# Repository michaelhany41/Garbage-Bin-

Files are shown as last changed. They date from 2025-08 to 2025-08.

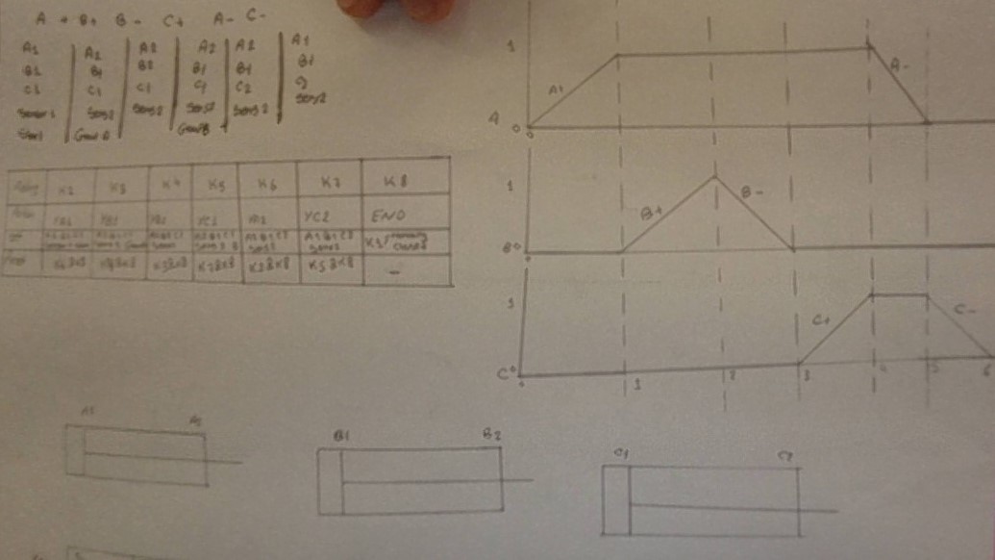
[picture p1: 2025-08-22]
step diagram1.jpg

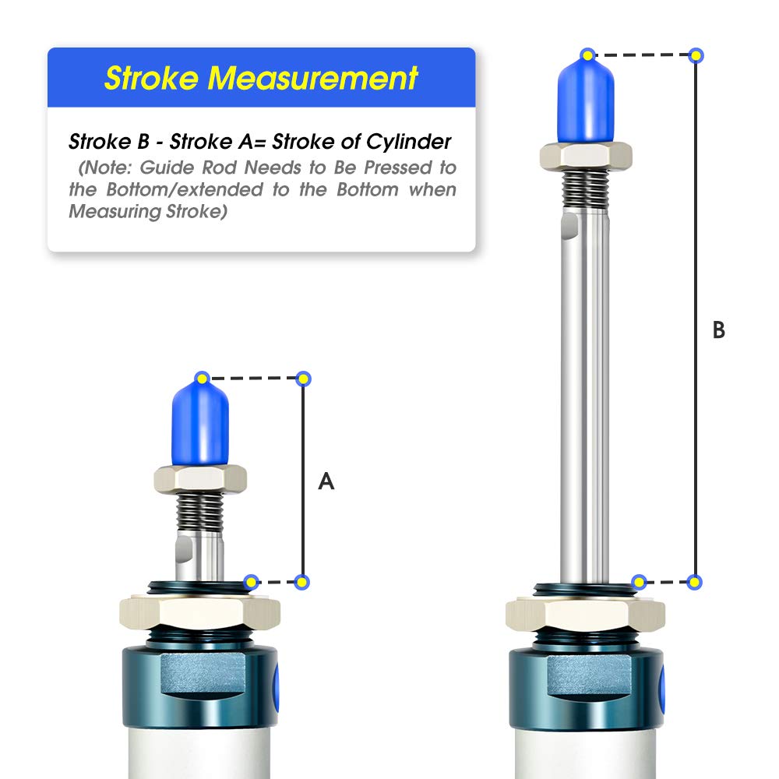
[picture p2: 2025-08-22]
SolidWorks design/Pneumatic Air Cylinder Double Action/3.jpg

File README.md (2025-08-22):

# Garbage-Bin-
This project showcases an automated garbage handling system using pneumatic cylinders, sensors, and relay-based control. The system detects garbage, pushes it into a crushing chamber, compresses it, and then disposes of it into a bin — all in a fully automated sequence.

⚙️ How It Works

Detection: Two photocell sensors detect incoming garbage.

Push to Crusher: Cylinder 1 pushes the garbage into the crushing chamber.

Crushing: Cylinder 2 compresses the garbage.

Disposal: Cylinder 3 ejects the compacted waste into a bin.

🛠️ Components

3 Pneumatic Cylinders

11 Relays

6 Reed Switches (2 per cylinder for position feedback)

2 Photocell Sensors

Solenoid Valves

Power Supply & Relay Logic

🧠 Control Logic

The system uses reed switches and relays to manage the sequence and ensure each cylinder operates only when safe. Relays control solenoids based on sensor input, enabling fully automated, reliable operation without a microcontroller.

📦 Applications

Ideal for educational automation demos, small-scale prototyping of waste management systems, or learning electropneumatics and sensor integration.

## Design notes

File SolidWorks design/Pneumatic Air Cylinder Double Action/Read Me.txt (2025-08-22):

This 3D model shows a pneumatic cylinder of four different sizes.
The cylinder length can be customized by adjusting the stroke using equations in SolidWorks for the Cylinder Barrel and Piston Rod.
Detailed stroke lengths are available in the provided "Product Description" PDF.

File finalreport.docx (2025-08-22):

# German University in Cairo

# Mechatronics Lab (MCTR704)

# Automated Garbage Bin

# Project No. [4]

Name: Michael Hany /Khaled Hussien

I.D #: 55-23395 /55-6752

Tutorial No.: 28

Table of Contents

Milestone No./ Submission Date | Content | Page
Milestone 1 23/09/2024 | Project Description……………………………………………………………….. | x-x
Milestone 1 23/09/2024 | SolidWorks Design: 3D Schematic Diagram………...................... | x-x
Milestone 2 14/10/2024 | Mechanical Components in 2D with Dimensions…………………… | x-x
Milestone 2 14/10/2024 | Mechanical Components List………………………………………………… | x-x
Milestone 3 11/11/2024 | Pneumatic Step Diagram………………………………………………………. | x-x
Milestone 3 11/11/2024 | Electro-Pneumatic Circuit……………………………………………………… | x-x
Milestone 4 09/12/2024 | Hardware Model (Electrical + Mechanical)……………………………. | x-x
Milestone 4 xx/12/2024 | Fully Operating Hardware (Final Evaluation)…………………………. | x-x

Project Description:

Dimensions:

Frame 90cm X 70cm X 90cm

Project Idea:

The Automated Garbage Bin consists of a compact machine with a sturdy, ground-seated frame that supports three hydraulic cylinders and integrated sensors. The frame holds all the necessary mechanical components, and the system is designed to manage garbage collection and compaction efficiently. Various actuators and sensors are used to automate the entire operation.

Objective:

This project aims to collect and compress garbage, reducing its volume for more efficient storage and disposal and save more space also for the environment

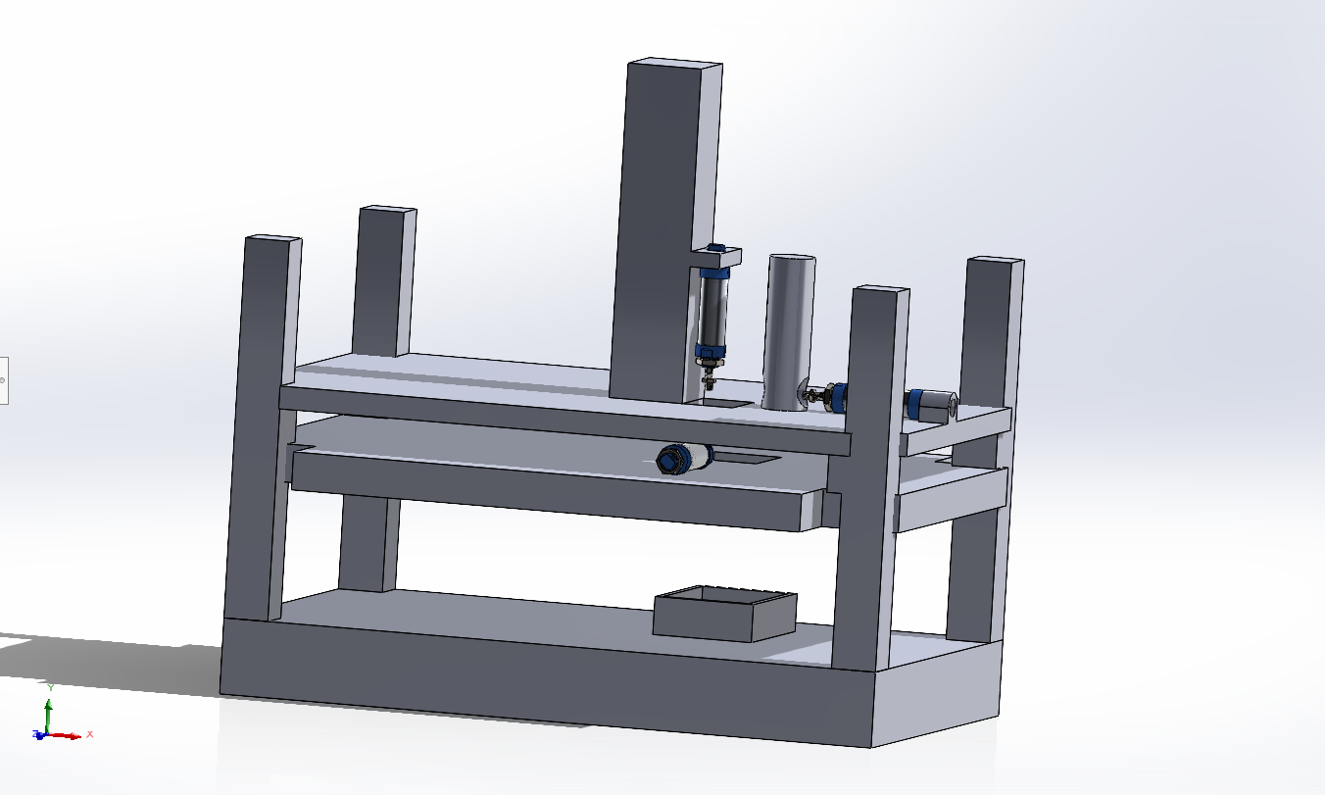
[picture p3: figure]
A 3d model of a machine with Willis Tower in the background

Process:

This machine features a ground-level frame that supports all mechanical components, including three hydraulic cylinders and various sensors. Here's how it works:

1. Garbage is placed into a container.
2. First, the garbage is dropped into the receiving container.
3. When the sensors sense the garbage the first cylinder [A] moves the garbage from the bin into a compression chamber.
4. The second cylinder [B] which is in a vertical mode, compresses the garbage.
5. Once compressed, the third cylinder ejects the compacted garbage from the machine to the trash.

SolidWorks Design: 3D Schematic Diagram

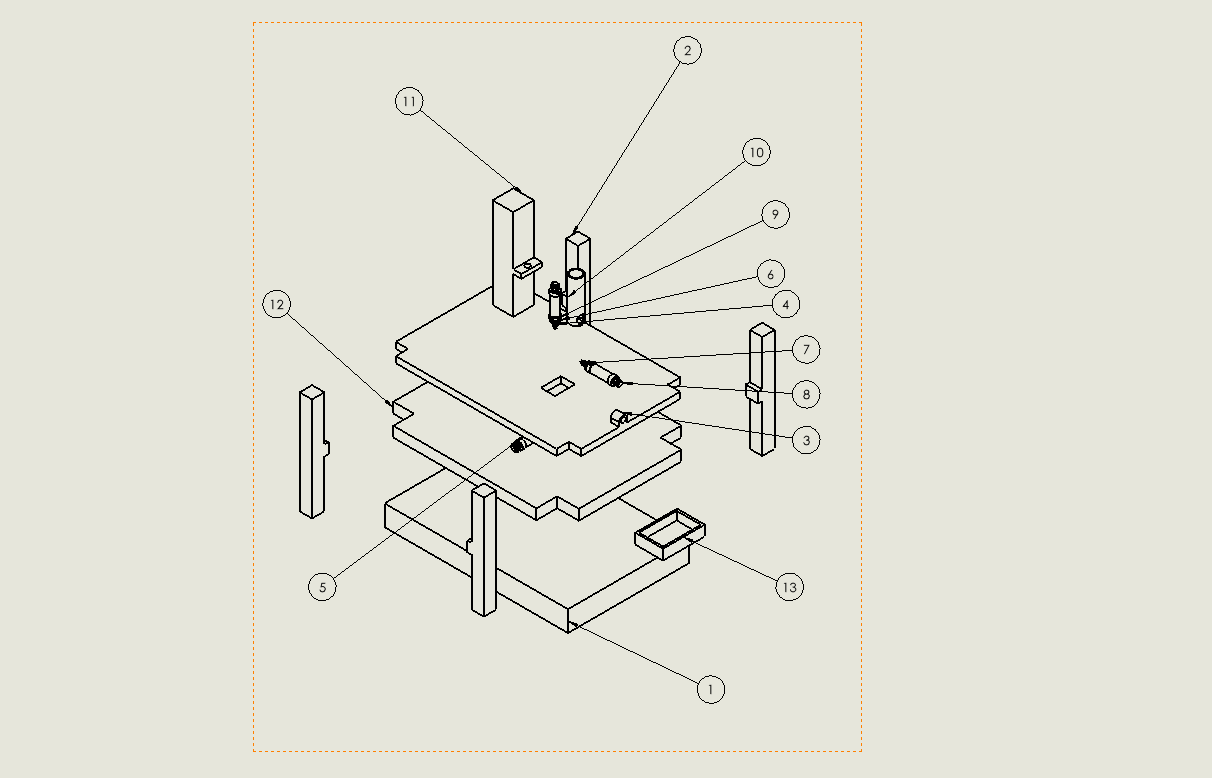
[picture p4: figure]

Part Number | Name | Quantity
1 | Ground base | 1
2 | Support Bar | 4
3 | Level 2 base | 3
4 | Cylinder A Piston | 1
5 | Cylinder C | 1
6 | Cylinder A | 1
7 | Cylinder B piston | 1
8 | Cylinder B | 1
9 | Cup Cylinder | 1
10 | Cylinder A nut | 1
11 | Cylinder B Holder | 1
12 | Level 1 base | 1
13 | Garbage basket | 1

Project Documentation Winter 20241Mechatronics Lab MCTR704

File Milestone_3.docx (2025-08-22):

# German University in Cairo

# Mechatronics Lab (MCTR704)

# Automated Garbage Bin

# Project No. [4]

Name: Michael Hany /Khaled Hussien

I.D #: 55-23395 /55-6752

Tutorial No.: 28

Table of Contents

Milestone No./ Submission Date | Content | Page
Milestone 1 23/09/2024 | Project Description……………………………………………………………….. | x-x
Milestone 1 23/09/2024 | SolidWorks Design: 3D Schematic Diagram………...................... | x-x
Milestone 2 14/10/2024 | Mechanical Components in 2D with Dimensions…………………… | x-x
Milestone 2 14/10/2024 | Mechanical Components List………………………………………………… | x-x
Milestone 3 11/11/2024 | Pneumatic Step Diagram………………………………………………………. | x-x
Milestone 3 11/11/2024 | Electro-Pneumatic Circuit……………………………………………………… | x-x
Milestone 4 09/12/2024 | Hardware Model (Electrical + Mechanical)……………………………. | x-x
Milestone 4 xx/12/2024 | Fully Operating Hardware (Final Evaluation)…………………………. | x-x

Project Description:

Dimensions:

Frame 90cm X 70cm X 90cm

Workpiece is a paper cup diameter 6.5cm and height 10cm

Project Idea:

The Automated Garbage Bin consists of a compact machine with a sturdy, ground-seated frame that supports three hydraulic cylinders and integrated sensors. The frame holds all the necessary mechanical components, and the system is designed to manage garbage collection and compaction efficiently. Various actuators and sensors are used to automate the entire operation.

Objective:

This project aims to collect and compress garbage, reducing its volume for more efficient storage and disposal and save more space also for the environment

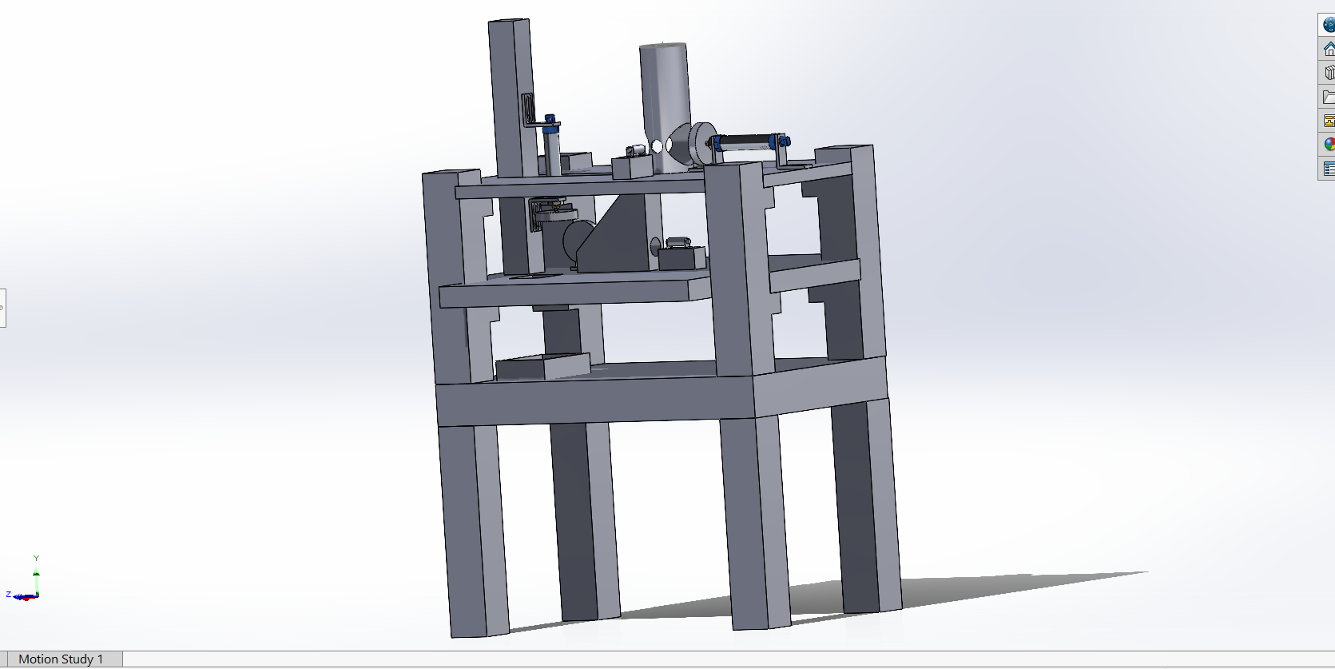
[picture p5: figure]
A grey machine with blue tubes

Process:

This machine features a ground-level frame that supports all mechanical components, including three hydraulic cylinders and various sensors. Here's how it works:

1. Garbage is placed into a container.
2. First, the garbage is dropped into the receiving container.
3. When the sensors sense the garbage the first cylinder [A] moves the garbage from the bin into a compression chamber.
4. The second cylinder [B] which is in a vertical mode, compresses the garbage.
5. Once compressed, the third cylinder ejects the compacted garbage from the machine to the trash.

SolidWorks Design: 3D Schematic Diagram

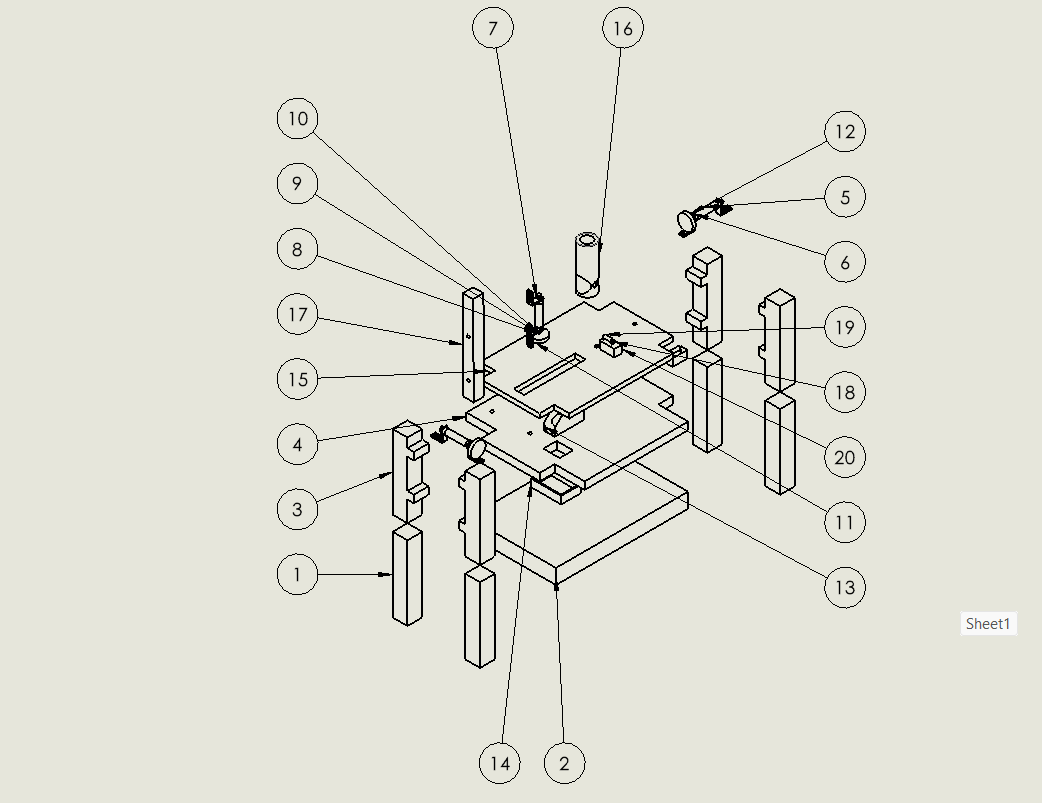
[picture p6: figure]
A diagram of a structure

Part Number | Name | Quantity
1 | Table leg | 4
2 | Ground base | 1
3 | Support bar | 4
4 | First level base | 1
5 | Cylinder A | 1
6 | bracket | 2
7 | Cylinder B | 1
8 | bracket | 6
9 | washer | 1
10 | End effector B | 1
11 | Nut | 1
12 | End effector A | 1
13 | Ramp | 1
14 | Garbage basket | 1
15 | Level 2 base | 1
16 | magazine | 1
17 | Cylinder B supporter | 1
18 | Sensor bracket | 4
19 | Sensor | 2
20 | Sensor Holder | 2

## Mechanical Components 2D Projections with Dimensions

Ramp

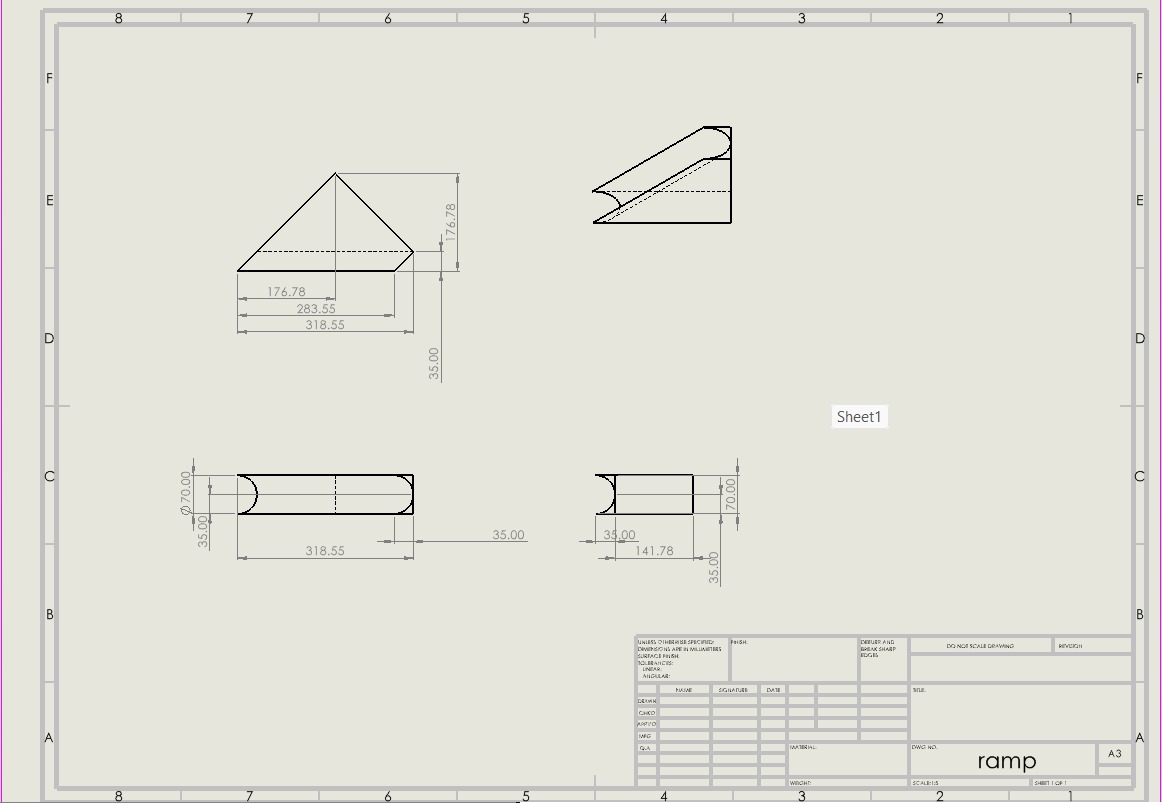
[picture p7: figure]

Supporter

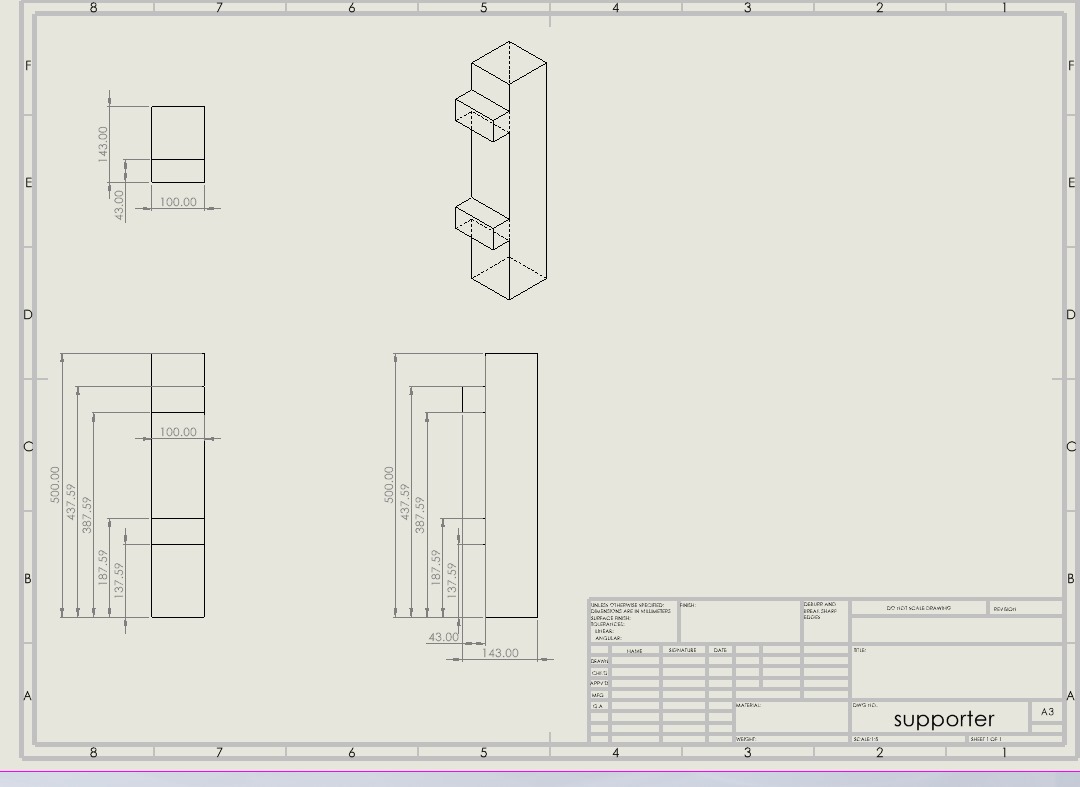
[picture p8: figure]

Tablet:

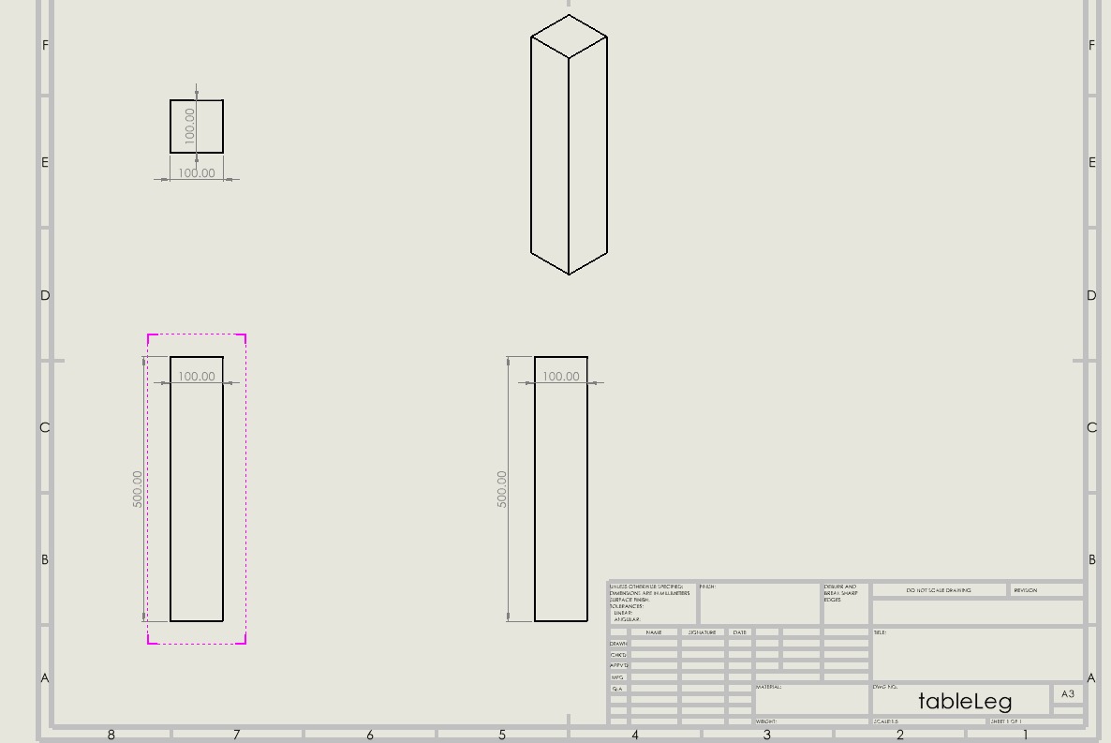
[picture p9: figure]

Cylinder Hold

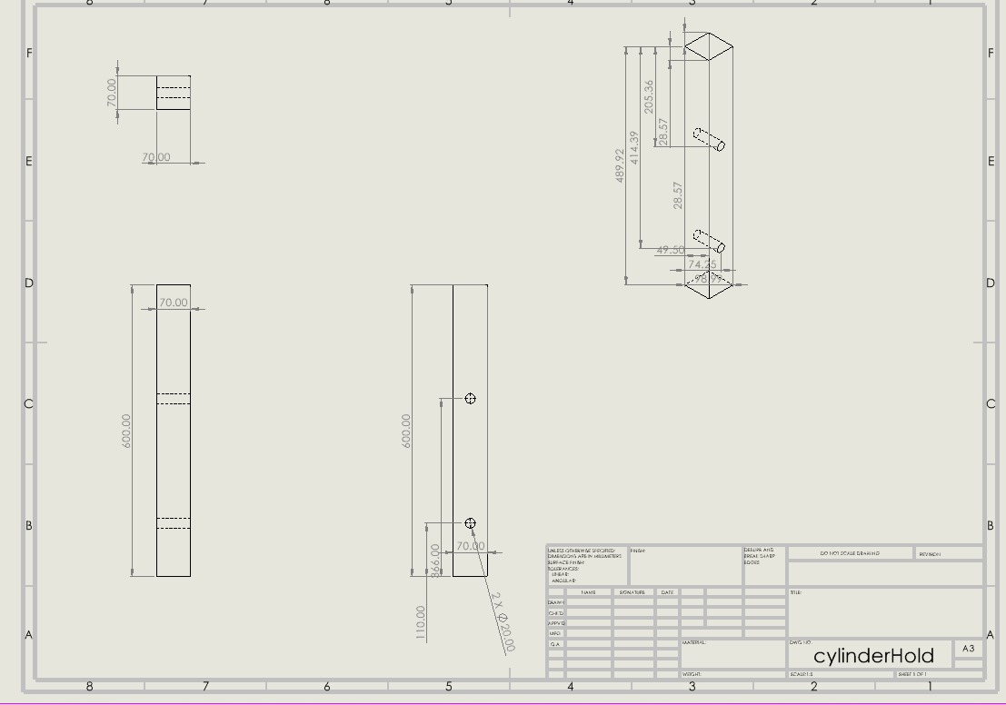
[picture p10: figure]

Base el Base

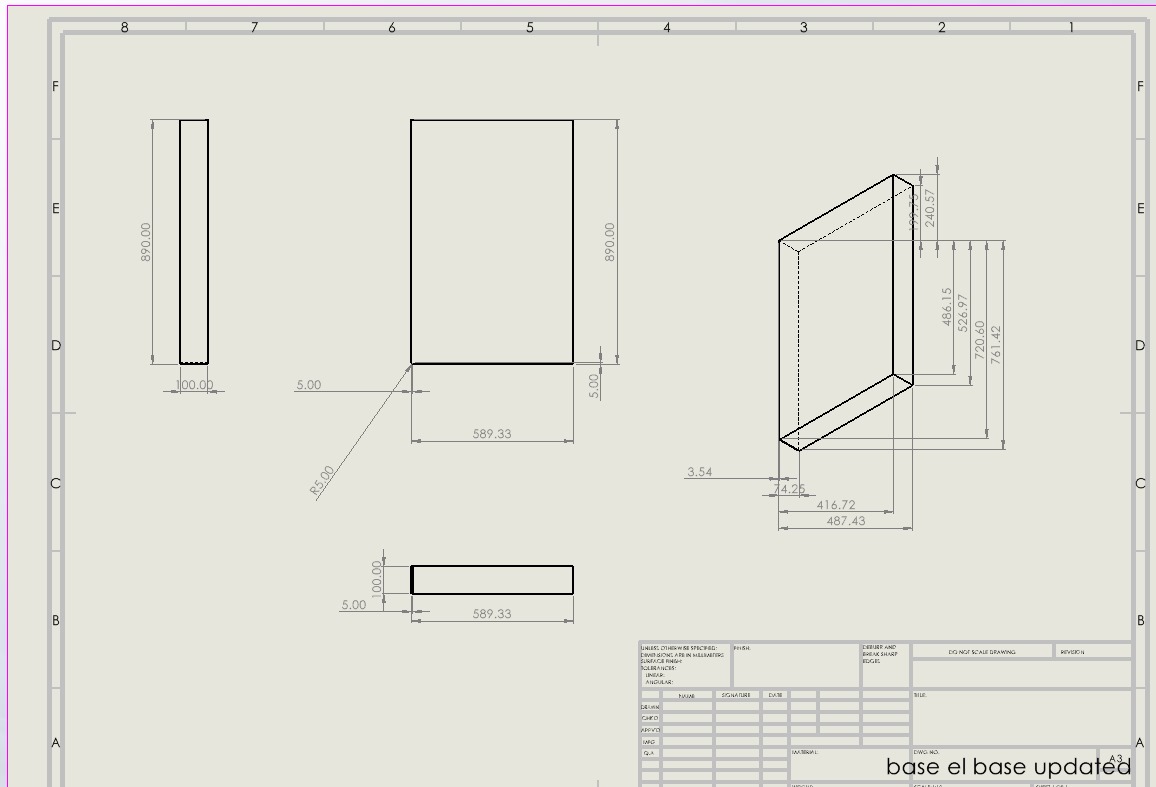
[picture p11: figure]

End Effector

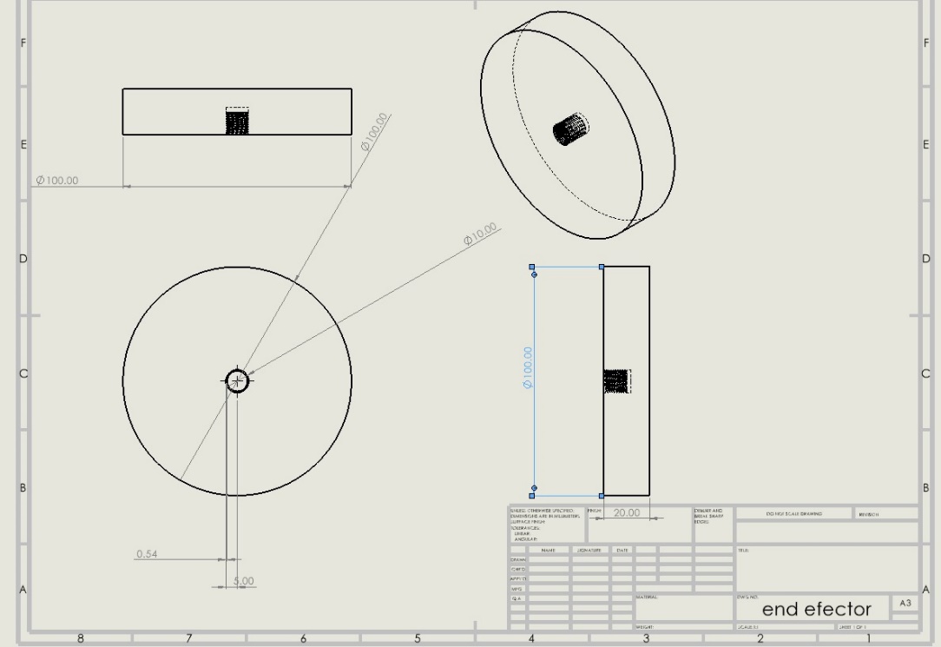
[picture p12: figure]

Pneumatic Air Cylinder Double Acting

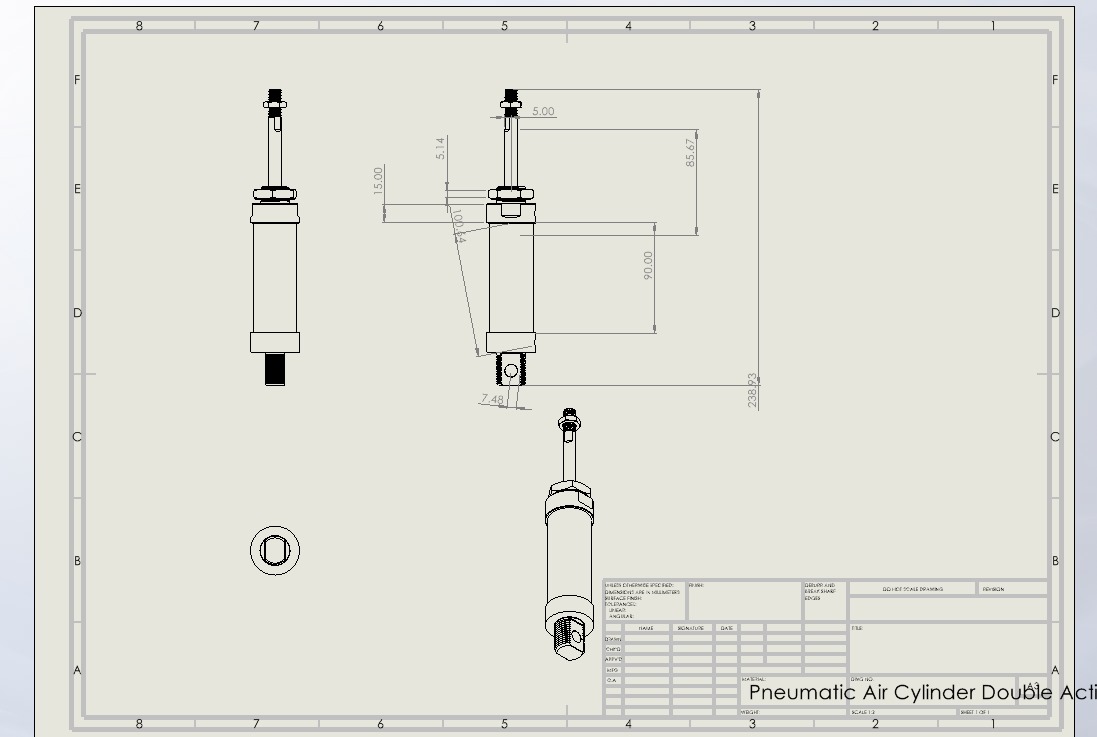
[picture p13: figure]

Base el Base

Bracket

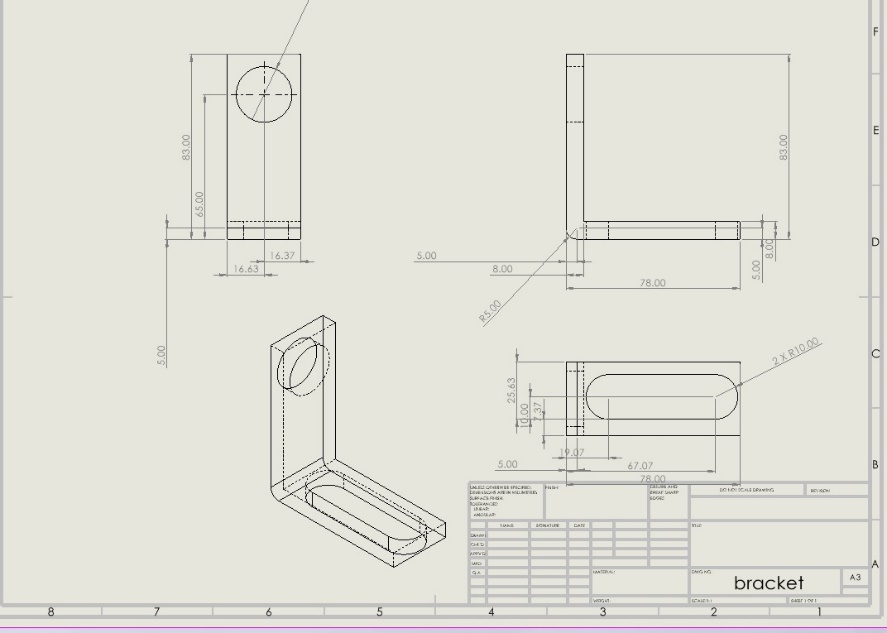
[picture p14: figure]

Magazine

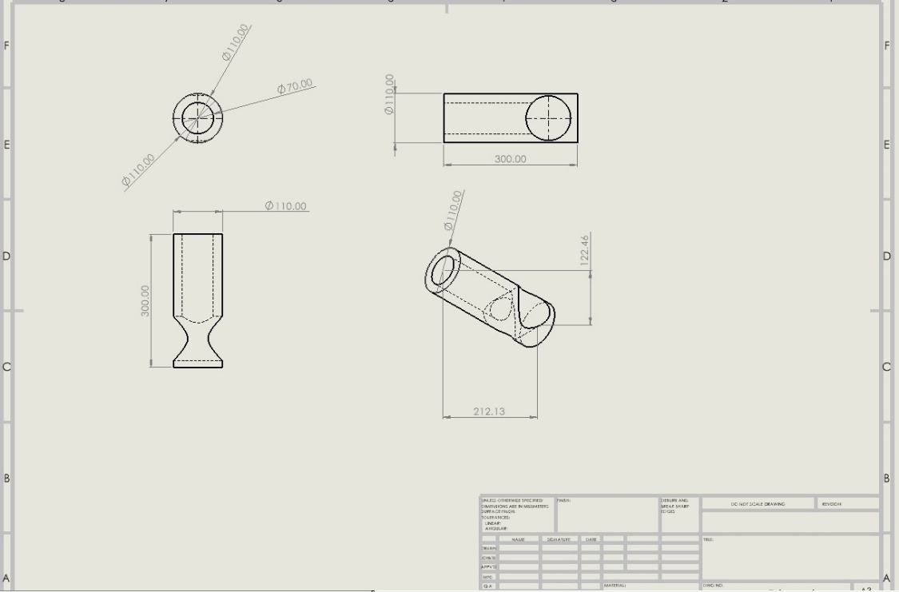
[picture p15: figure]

Sensor

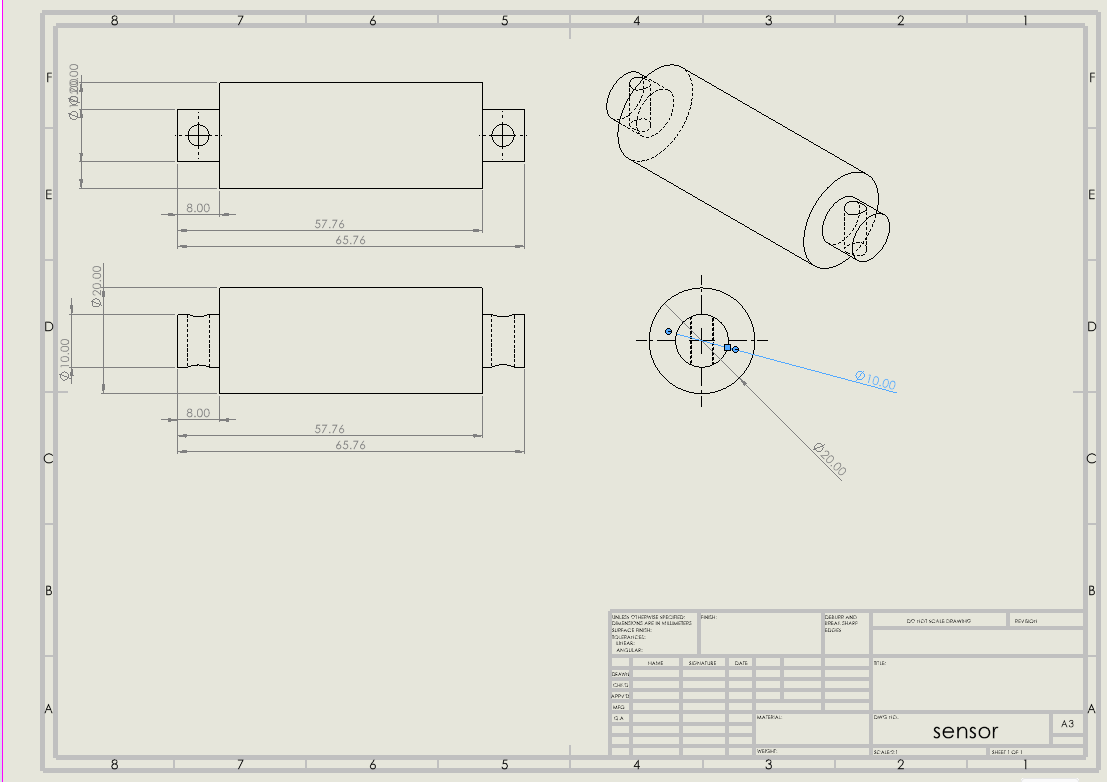
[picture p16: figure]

+

Component’s List:

Component’s Name | Picture | Quantity And Functions

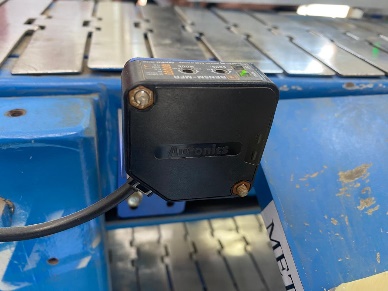
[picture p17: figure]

Photoelectric Sensor (ben5m-mfr) | | 2 Function: To detect the garbage and send electrical signal to the cylinder to function it

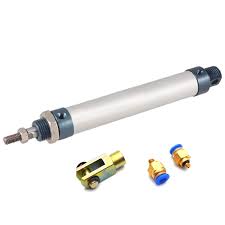
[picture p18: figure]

Pneumatic air cylinder double action | | 3 Function : Are used to transport and compress the gargbage

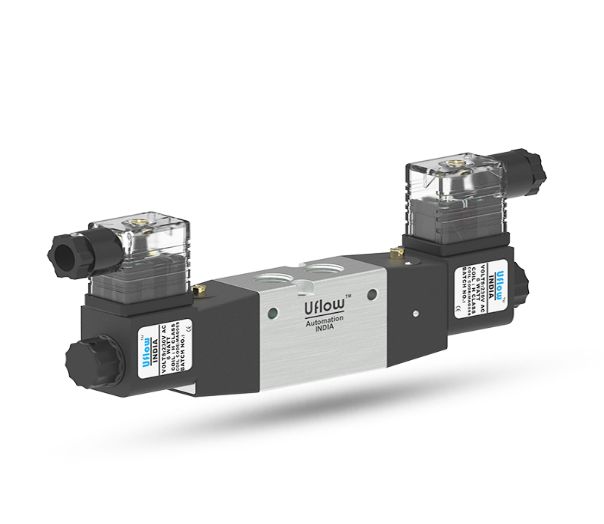
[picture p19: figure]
A close-up of a machine

5/2 pneumatic valves | | 3 Function : restore the pulses and make it continues

Pneumatic step diagram and description

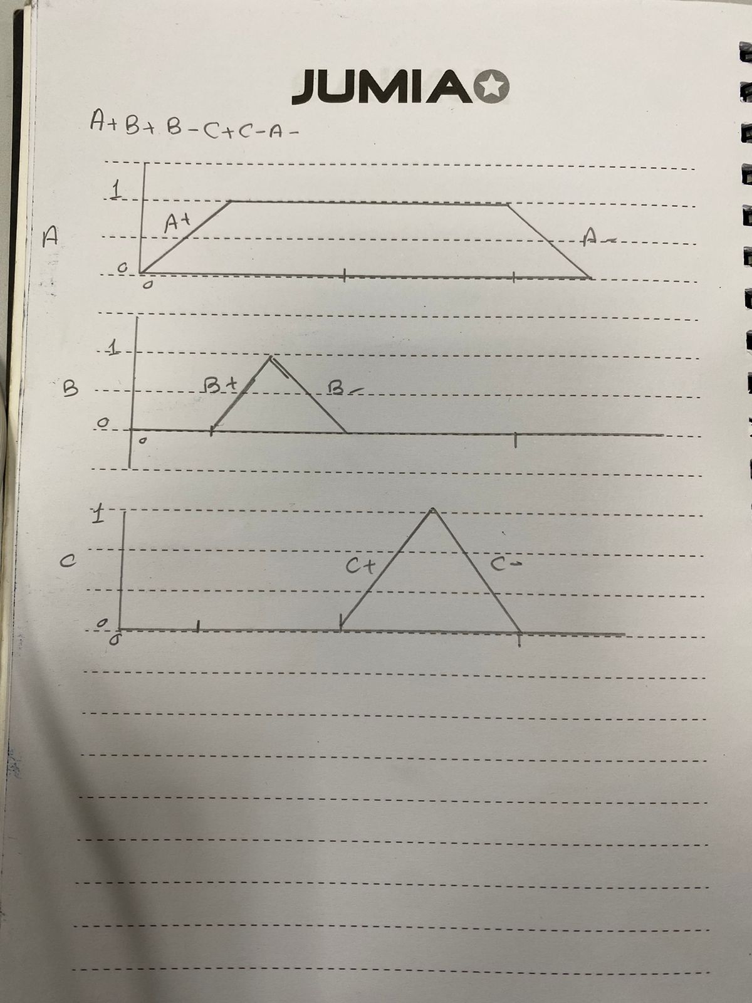
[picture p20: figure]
A notebook with lines drawn on it

As shown in figure the operation will start with Cylinder A extend

Then cylinder B will crash the object by extending then retracting

And Cylinder C will get rid of the object by extending

Then Cylinder A will retract after it ,Cylinder C will retract to start again the sequence

Electro pneumatic circuit

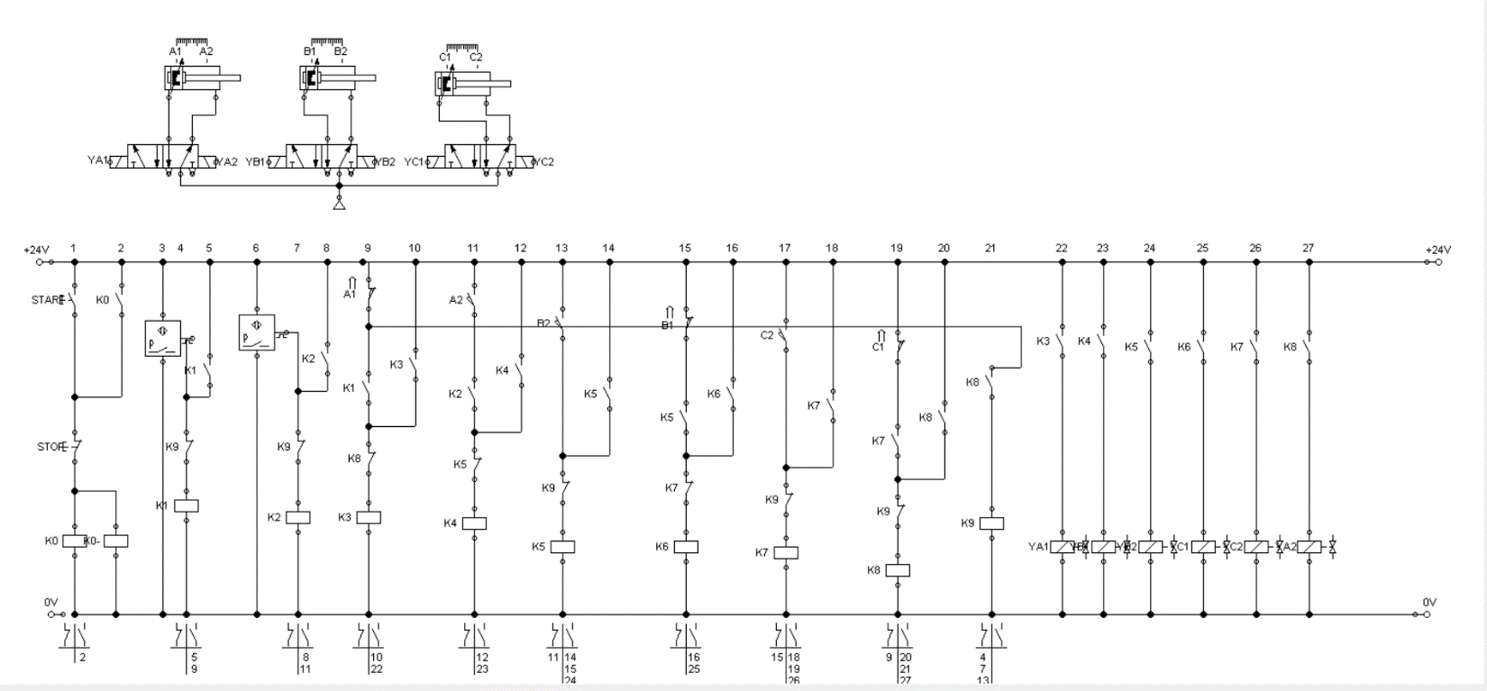
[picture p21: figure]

Hardware Model (Electrical + Mechanical):

Frame:

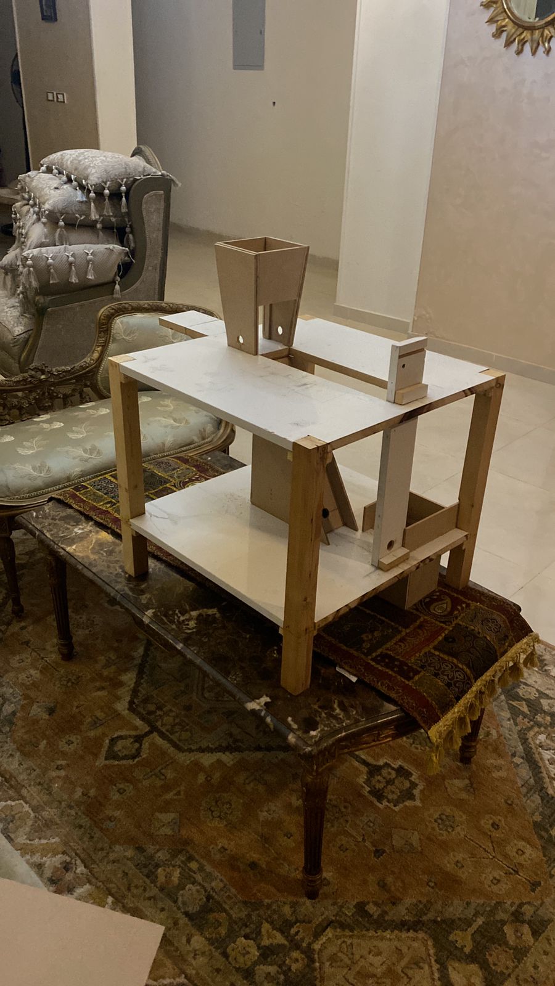
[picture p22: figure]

Control panel:

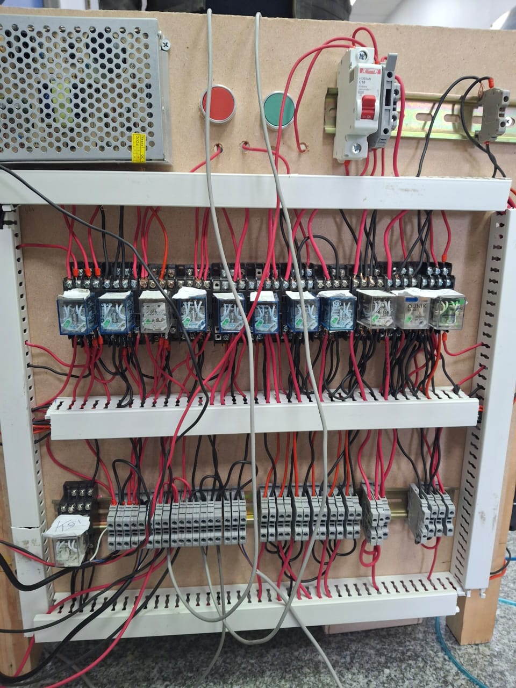
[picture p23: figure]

Final hardware:

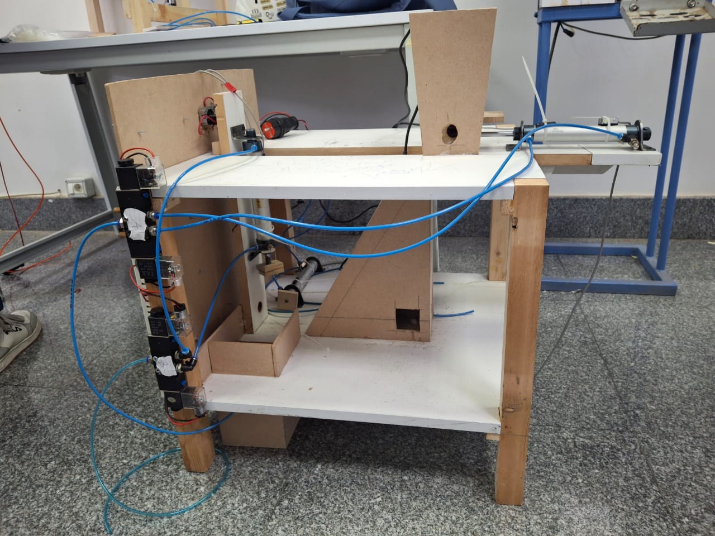
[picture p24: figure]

Project Documentation Winter 20241Mechatronics Lab MCTR704

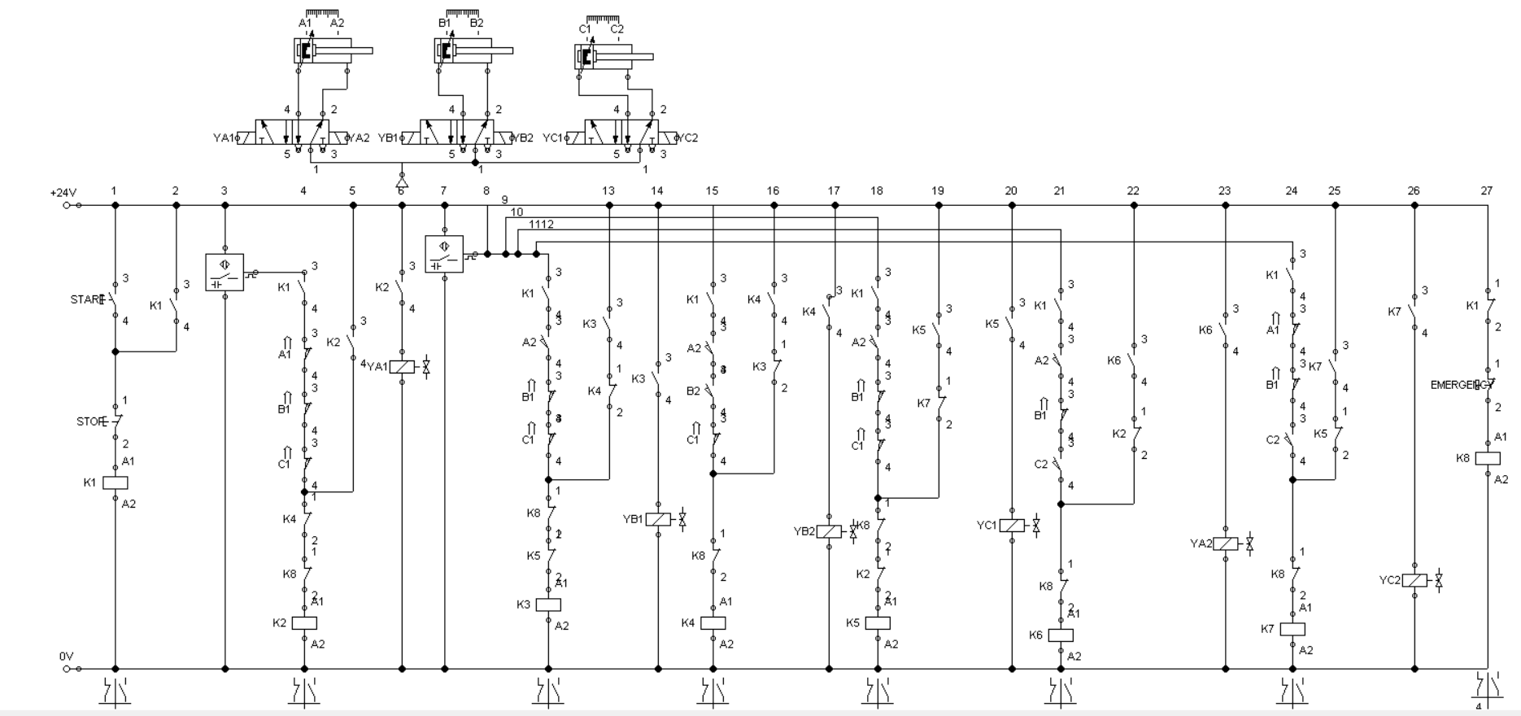
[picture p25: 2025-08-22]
project classic1.png

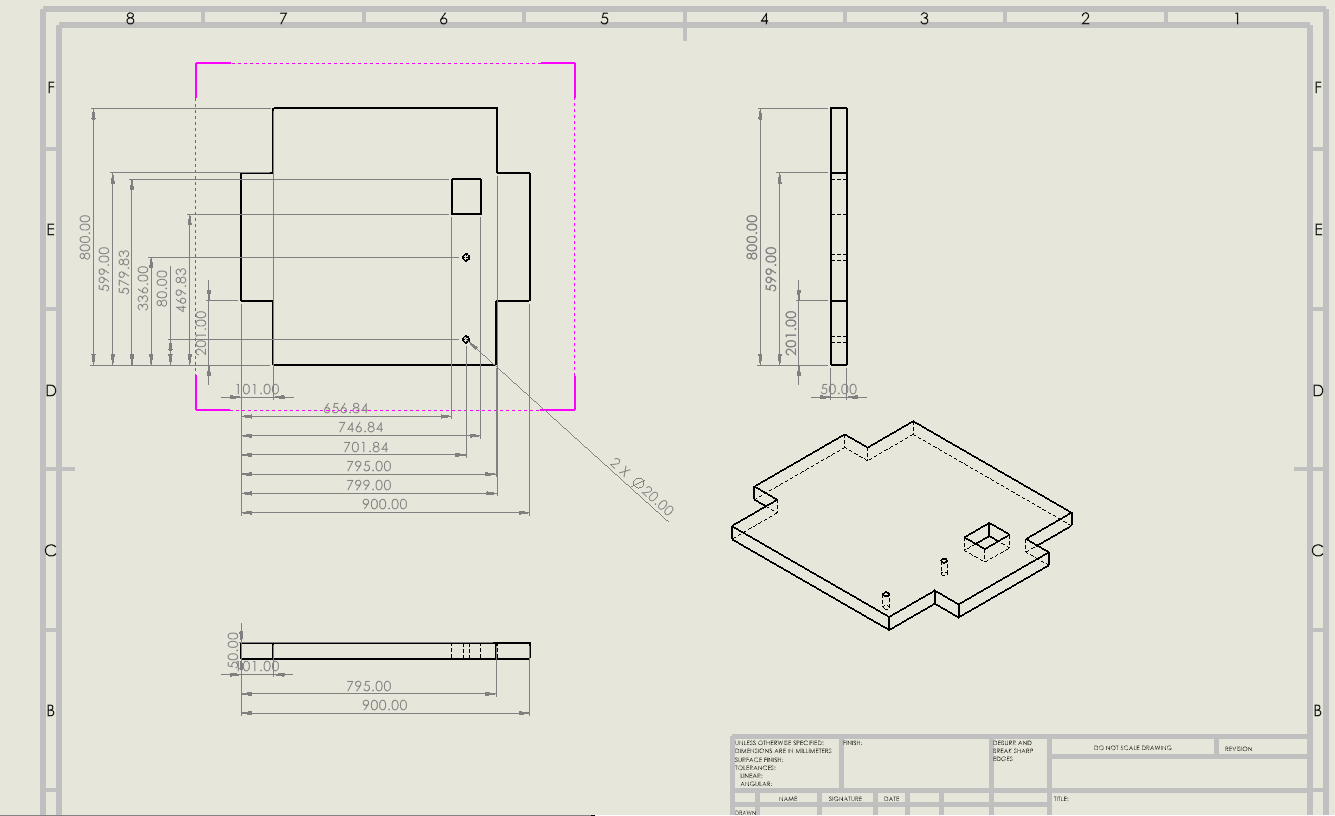
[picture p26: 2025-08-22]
2D drawing/base level1.png

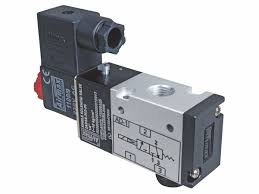
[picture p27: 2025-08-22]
2D drawing/download (1).jpeg

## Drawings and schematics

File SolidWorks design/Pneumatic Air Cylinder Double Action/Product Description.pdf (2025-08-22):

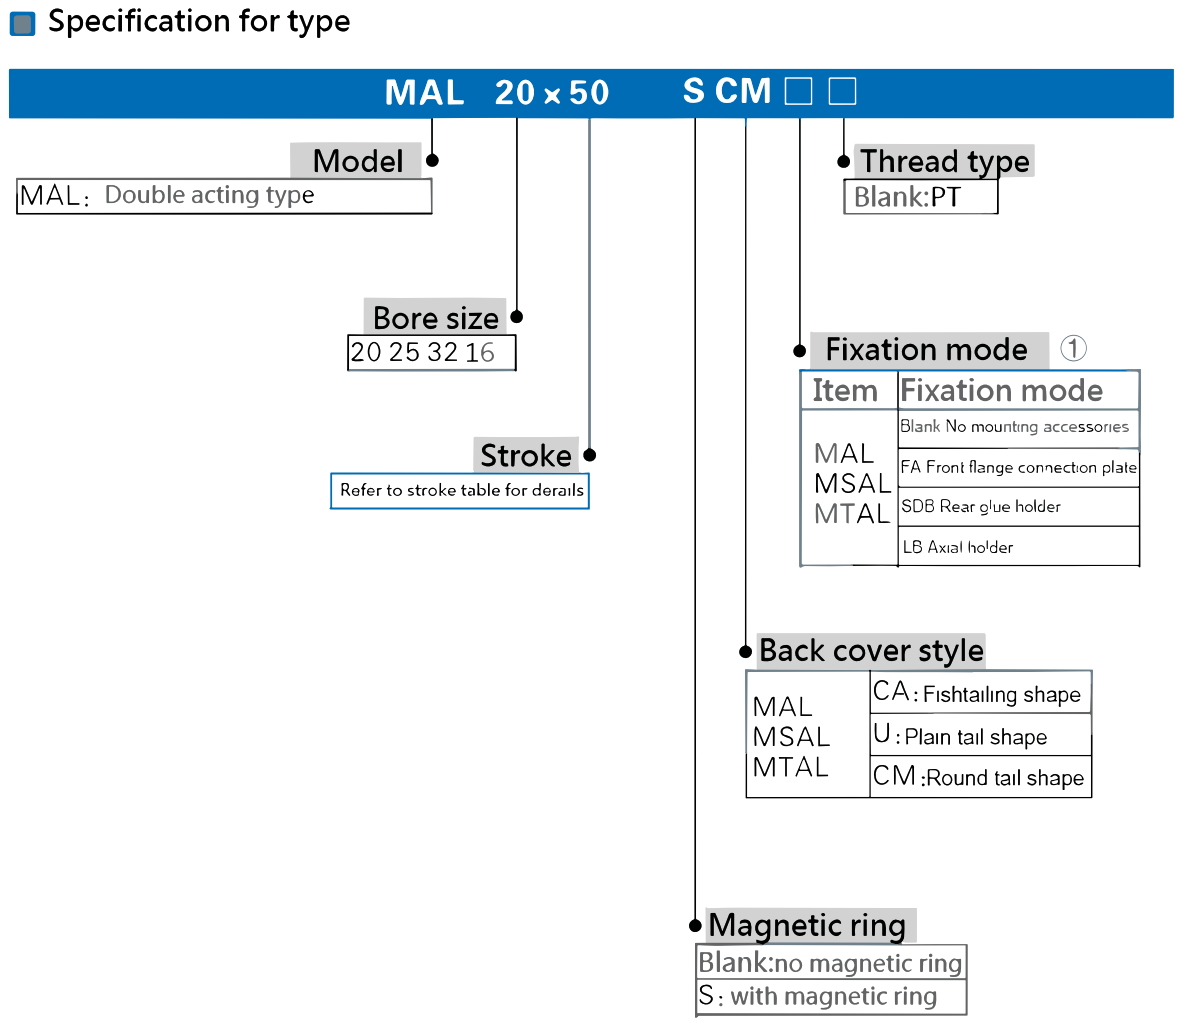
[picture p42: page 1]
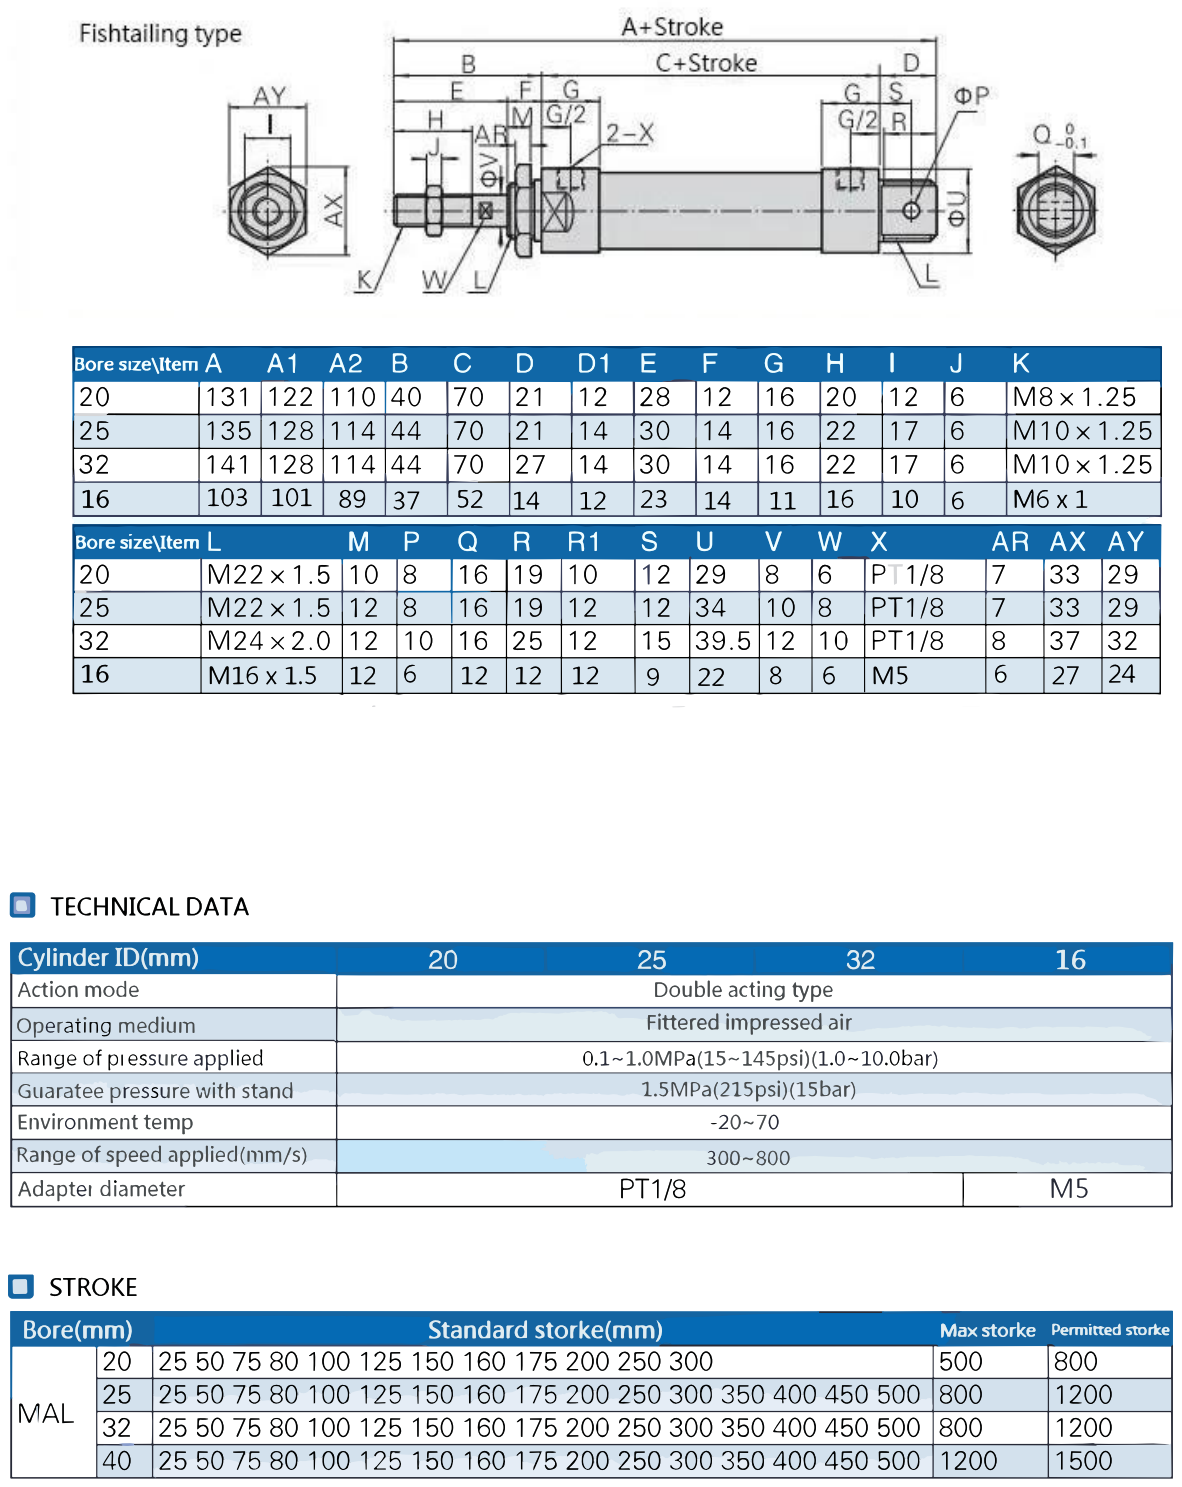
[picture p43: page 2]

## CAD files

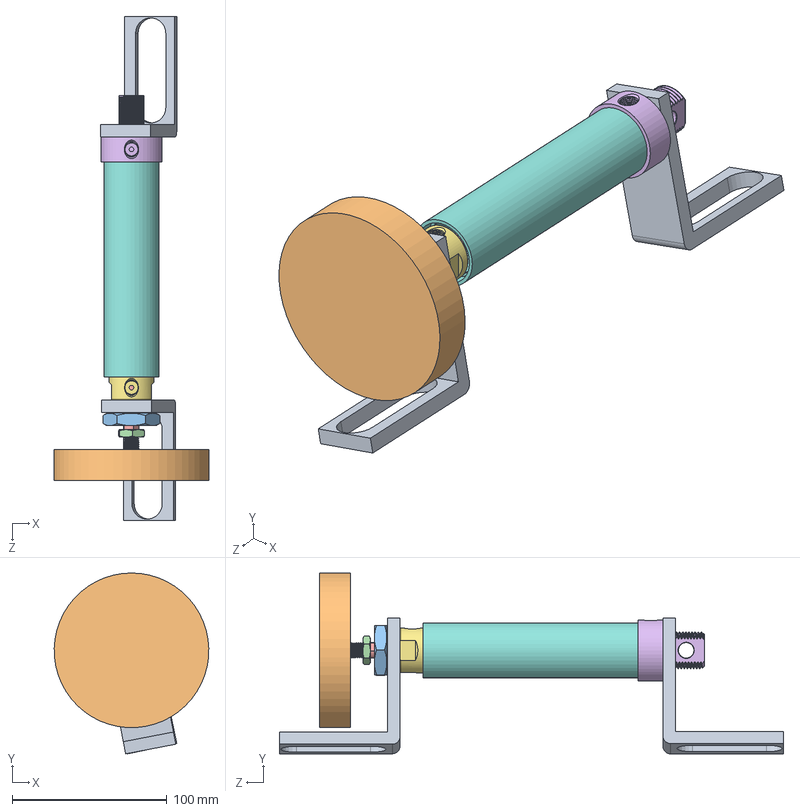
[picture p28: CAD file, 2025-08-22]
SolidWorks design/Pneumatic Air Cylinder Double Action/Pneumatic Air Cylinder Double Action.SLDASM
100.0 x 117.0 x 326.0 mm
Cylinder Barrel
Front Cap
Back Cap
Piston Rod
Hex Jam Nuts (Piston)
Hex Jam Nuts (Front Cap)
end efector
bracket x 2

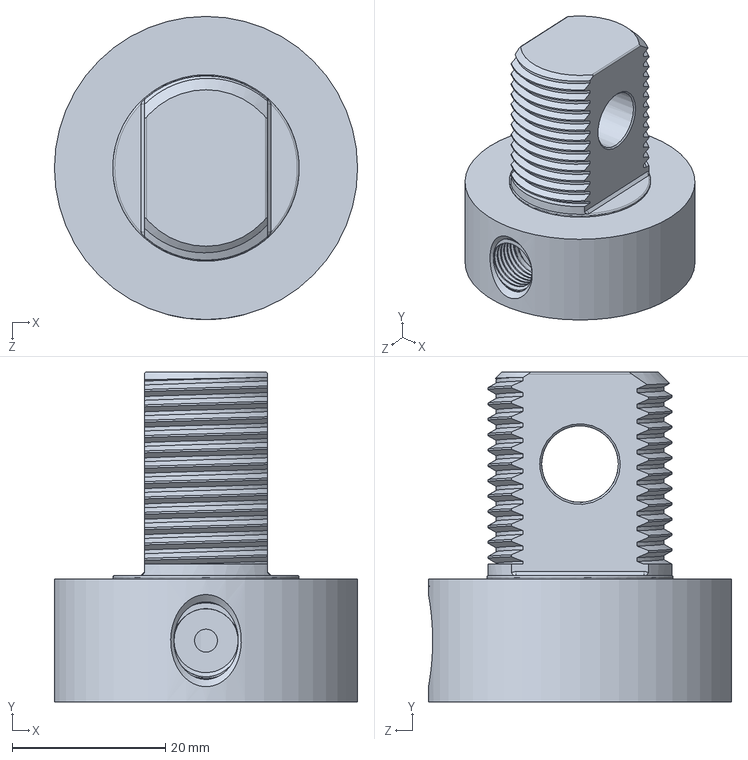
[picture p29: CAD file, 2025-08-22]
SolidWorks design/Pneumatic Air Cylinder Double Action/Back Cap.SLDPRT
39.5 x 43.0 x 39.5 mm

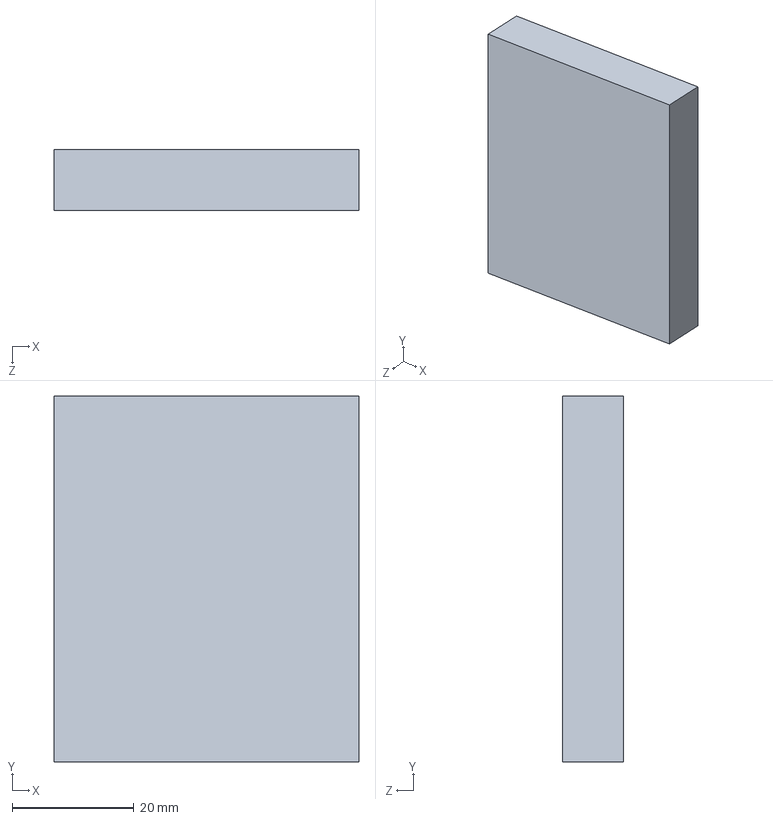
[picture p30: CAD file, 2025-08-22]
SolidWorks design/part 7 base.SLDPRT
50.0 x 60.0 x 10.0 mm

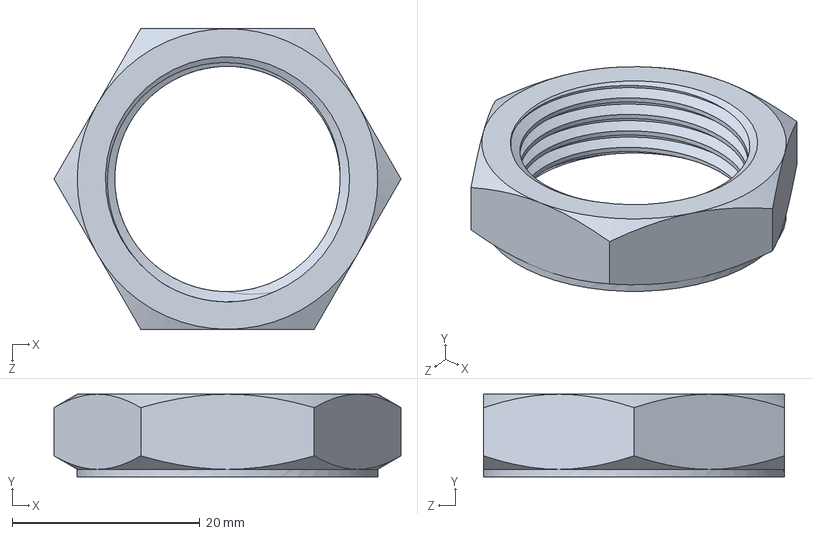
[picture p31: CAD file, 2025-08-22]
SolidWorks design/Pneumatic Air Cylinder Double Action/Hex Jam Nuts (Front Cap).SLDPRT
37.0 x 8.80 x 32.0 mm

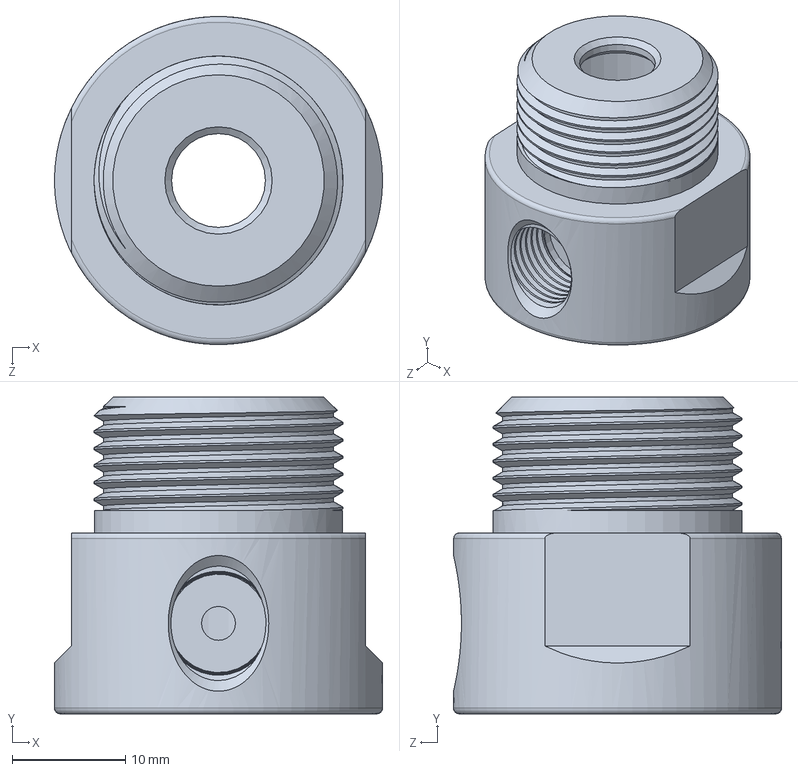
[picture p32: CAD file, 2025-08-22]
SolidWorks design/Pneumatic Air Cylinder Double Action/Front Cap.SLDPRT
29.0 x 28.0 x 29.0 mm

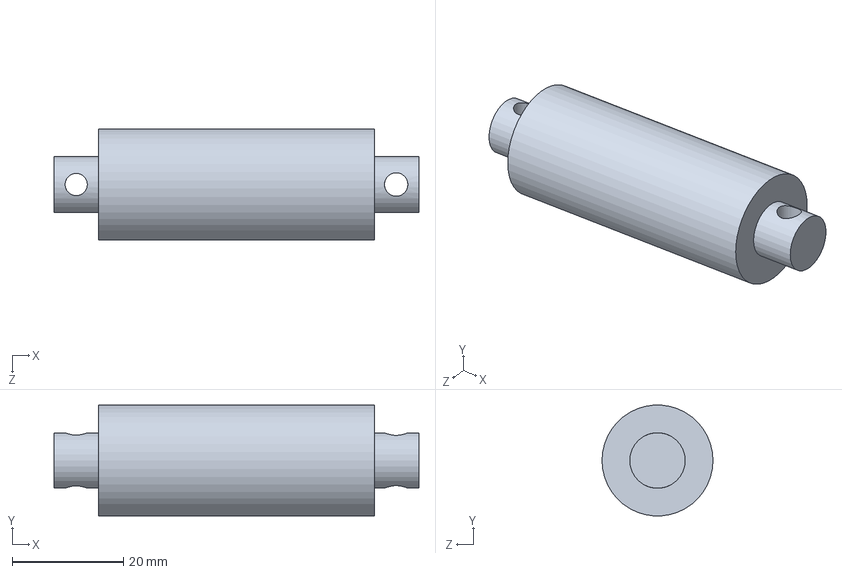
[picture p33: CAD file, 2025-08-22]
SolidWorks design/sensor.SLDPRT
65.8 x 19.9 x 20.0 mm

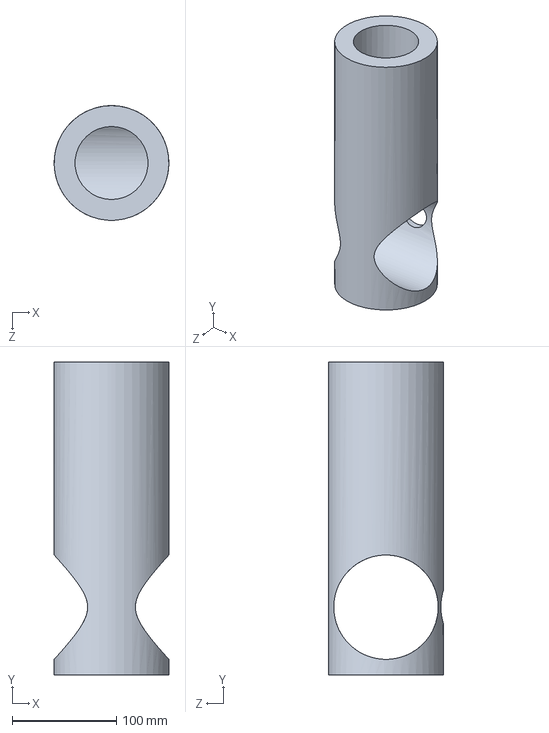
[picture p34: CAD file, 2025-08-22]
SolidWorks design/cupClynder.SLDPRT
110.0 x 300.0 x 110.0 mm

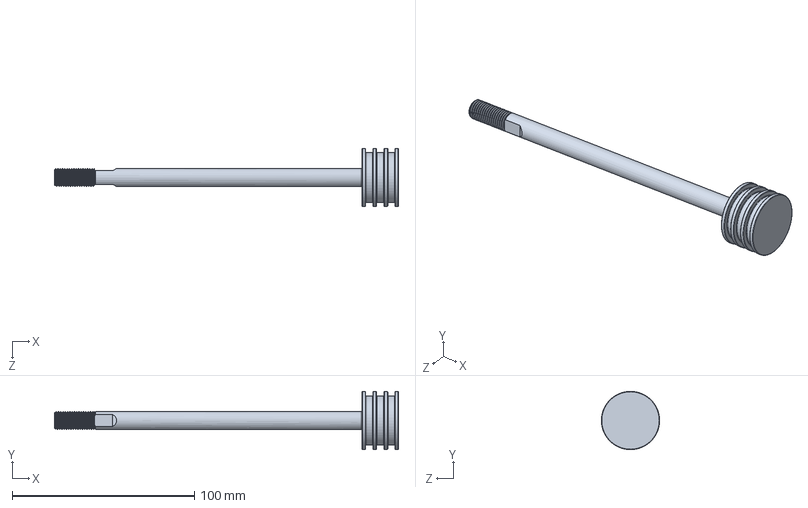
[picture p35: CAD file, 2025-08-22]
SolidWorks design/Pneumatic Air Cylinder Double Action/Piston Rod.SLDPRT
189.0 x 32.0 x 32.0 mm

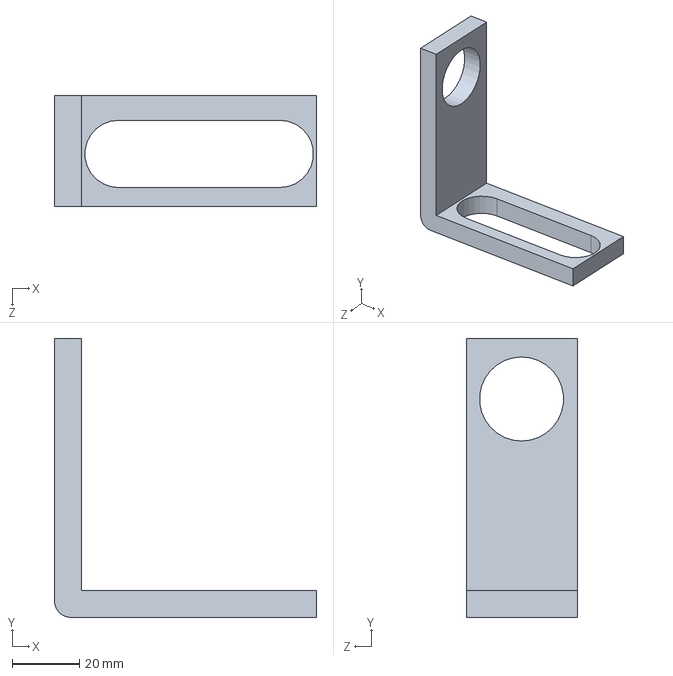
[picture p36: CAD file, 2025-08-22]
SolidWorks design/bracket.SLDPRT
78.0 x 83.0 x 33.0 mm

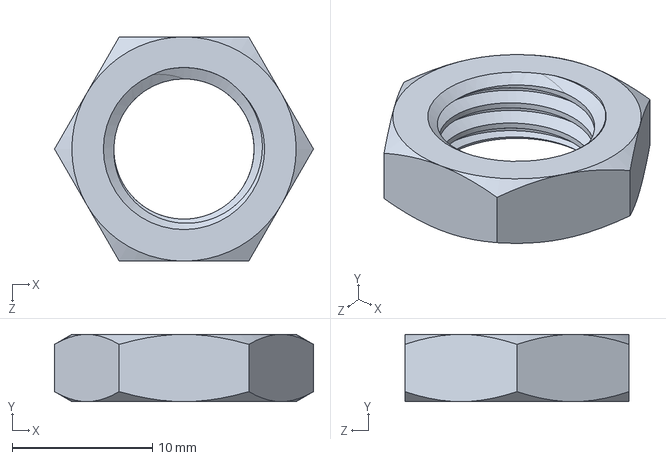
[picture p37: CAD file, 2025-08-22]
SolidWorks design/Pneumatic Air Cylinder Double Action/Hex Jam Nuts (Piston).SLDPRT
18.5 x 4.80 x 16.0 mm

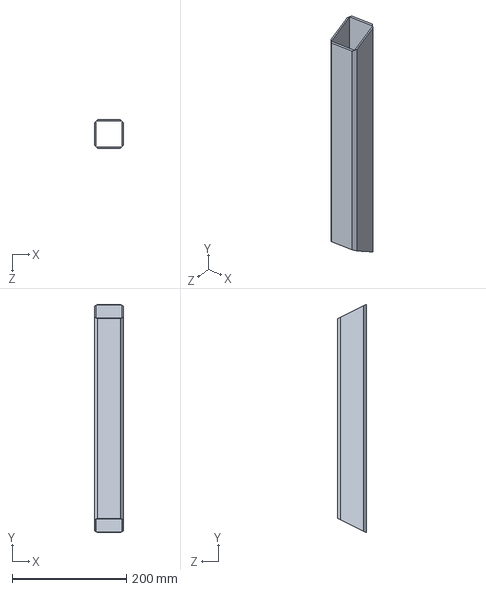
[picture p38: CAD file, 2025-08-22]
SolidWorks design/part 2 updated.SLDPRT
50.0 x 400.0 x 50.0 mm

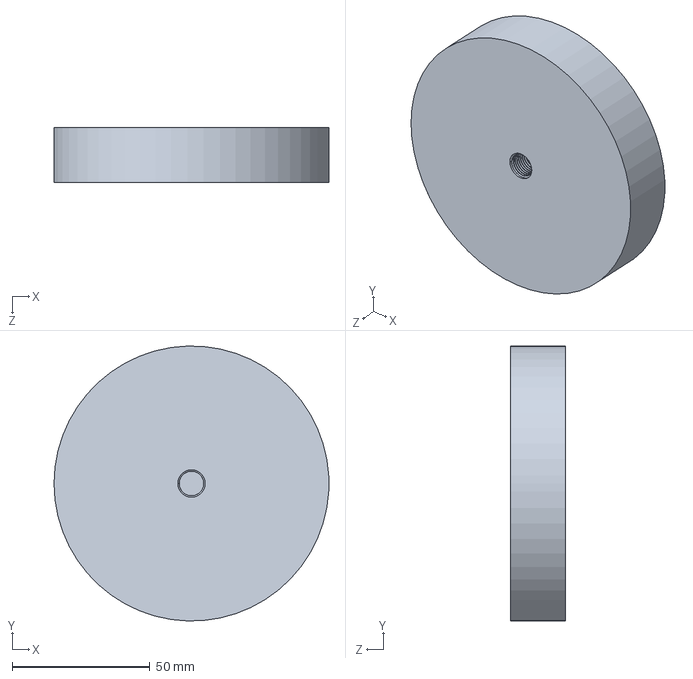
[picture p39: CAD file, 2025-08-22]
SolidWorks design/Pneumatic Air Cylinder Double Action/end efector.SLDPRT
100.0 x 100.0 x 20.0 mm

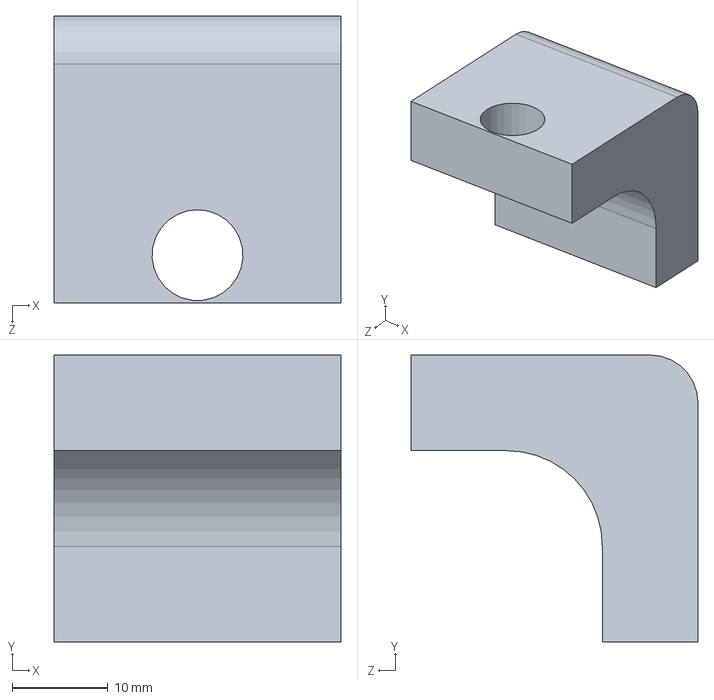
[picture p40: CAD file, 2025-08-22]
SolidWorks design/Part5.SLDPRT
30.0 x 30.0 x 30.0 mm

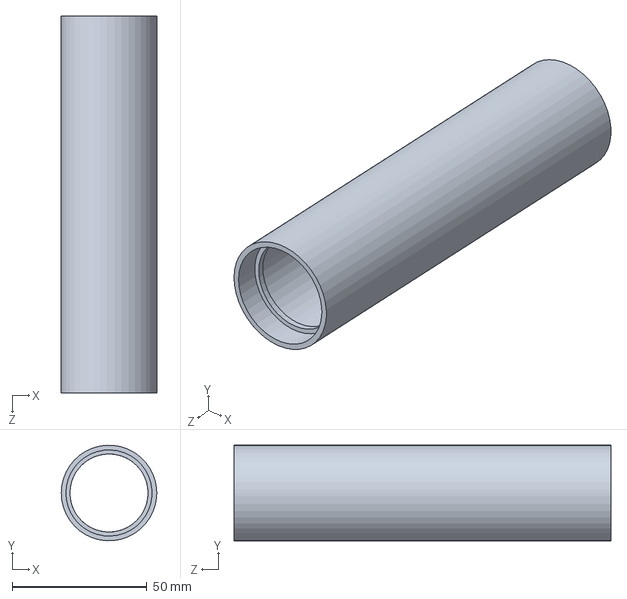
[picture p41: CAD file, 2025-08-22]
SolidWorks design/Pneumatic Air Cylinder Double Action/Cylinder Barrel.SLDPRT
35.5 x 35.5 x 140.0 mm

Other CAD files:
SolidWorks design/FinalDesign.SLDASM
SolidWorks design/Assembly 1.SLDASM
SolidWorks design/mini bracket.SLDPRT
SolidWorks design/stand.SLDPRT
SolidWorks design/2d drawing/Pneumatic Air Cylinder Double Action.SLDDRW
SolidWorks design/2d drawing/base el base updated.SLDDRW
SolidWorks design/2d drawing/base level1.SLDDRW
SolidWorks design/2d drawing/bracket.SLDDRW
SolidWorks design/2d drawing/cupClynder.SLDDRW
SolidWorks design/2d drawing/cylinderHold.SLDDRW
SolidWorks design/2d drawing/end efector.SLDDRW
SolidWorks design/2d drawing/ramp.SLDDRW
SolidWorks design/2d drawing/sensor.SLDDRW
SolidWorks design/2d drawing/supporter.SLDDRW
SolidWorks design/2d drawing/tableLeg.SLDDRW
SolidWorks design/Base el Base.SLDPRT
SolidWorks design/FinalDesign.SLDDRW
SolidWorks design/Part 2.SLDPRT
SolidWorks design/Part 3 Link el 3ard.SLDPRT
SolidWorks design/Part 4 Link 3ard tanya.SLDPRT
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
